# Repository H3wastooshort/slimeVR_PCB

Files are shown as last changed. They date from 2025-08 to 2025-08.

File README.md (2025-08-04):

# some kind of SlimeVR project

a rendered animation of the PCB roatating

## Schematic
the schematic

## PCB
a rendered image of the PCB front
a rendered image of the PCB back

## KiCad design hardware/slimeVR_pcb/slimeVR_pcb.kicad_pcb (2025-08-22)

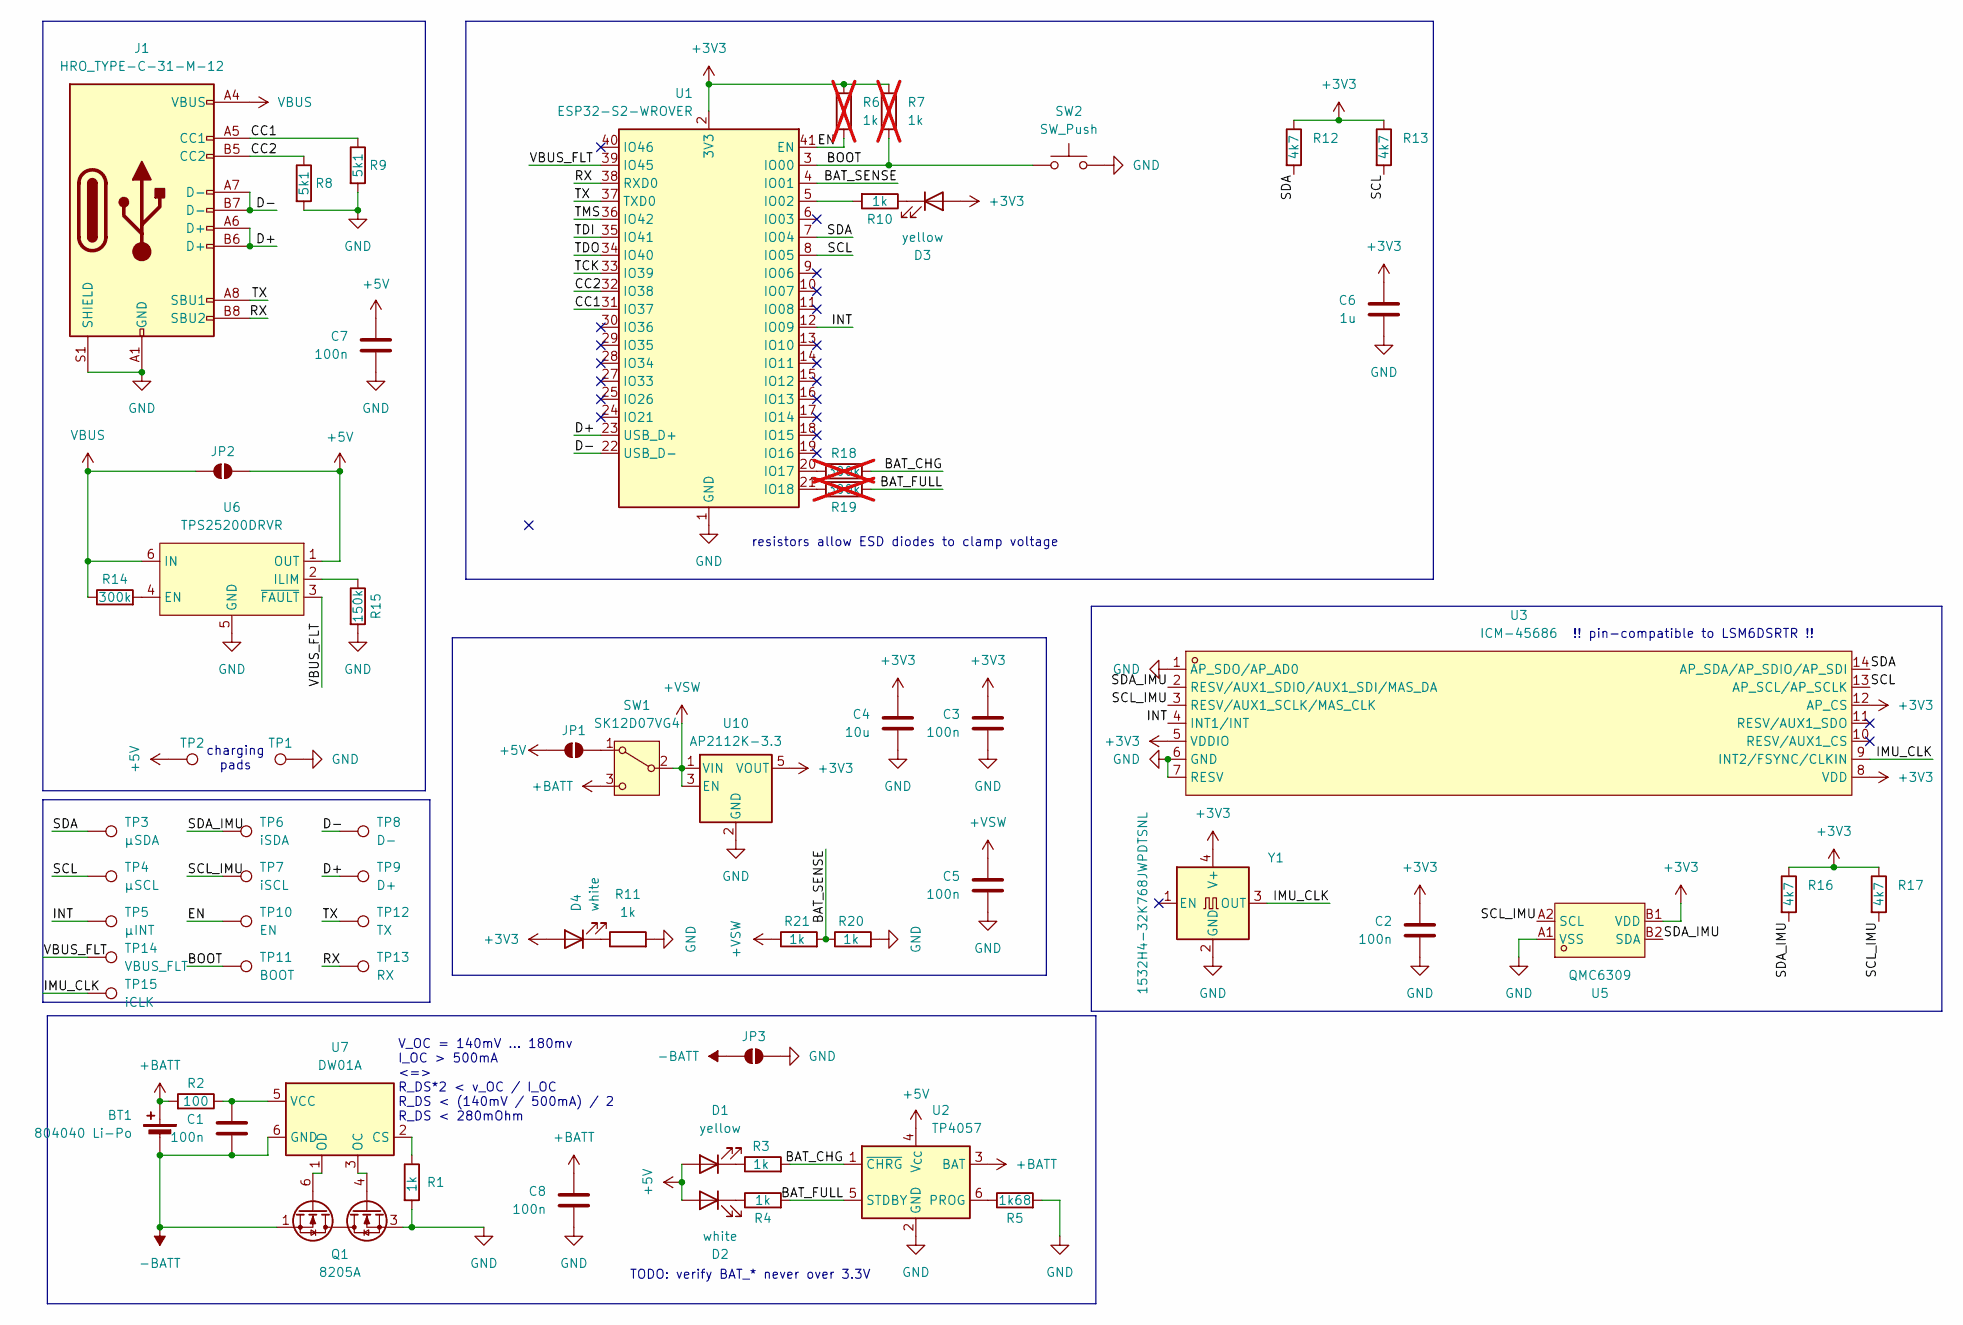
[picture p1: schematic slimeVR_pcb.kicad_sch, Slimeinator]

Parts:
BT1: 804040 Li-Po; JST_EH_B2B-EH-A_1x02_P2.50mm_Vertical
C1, C2, C3, C5, C7, C8: 100n; C_0603_1608Metric_Pad1.08x0.95mm_HandSolder; LCSC C14663
C4: 10u; C_0603_1608Metric_Pad1.08x0.95mm_HandSolder; LCSC C19702
C6: 1u; C_0603_1608Metric_Pad1.08x0.95mm_HandSolder; LCSC C15849
D1, D3: yellow; LED_0805_2012Metric_Pad1.15x1.40mm_HandSolder; LCSC C2296
D2, D4: white; LED_0805_2012Metric_Pad1.15x1.40mm_HandSolder; LCSC C34499
J1: HRO_TYPE-C-31-M-12; USB_C_Receptacle_HRO_TYPE-C-31-M-12; LCSC Part C165948
JP1, JP2, JP3: SolderJumper_2_Open; SolderJumper-2_P1.3mm_Open_TrianglePad1.0x1.5mm
Q1: 8205A; SOT-23-6; LCSC Part C2762931
R1, R3, R4, R10, R11, R20, R21: 1k; R_0603_1608Metric_Pad0.98x0.95mm_HandSolder; LCSC C21190
R2: 100; R_0603_1608Metric_Pad0.98x0.95mm_HandSolder; LCSC C22775
R5: 1k68; R_0603_1608Metric_Pad0.98x0.95mm_HandSolder; LCSC C4177
R6, R7: 1k; R_0603_1608Metric_Pad0.98x0.95mm_HandSolder; LCSC C21190; not fitted
R8, R9: 5k1; R_0603_1608Metric_Pad0.98x0.95mm_HandSolder; LCSC C23186
R12, R13, R16, R17: 4k7; R_0603_1608Metric_Pad0.98x0.95mm_HandSolder; LCSC C23162
R14: 300k; R_0603_1608Metric_Pad0.98x0.95mm_HandSolder; LCSC C23024
R15: 150k; R_0603_1608Metric_Pad0.98x0.95mm_HandSolder; LCSC C22807
R18, R19: 300k; R_0603_1608Metric_Pad0.98x0.95mm_HandSolder; LCSC C23024; not fitted
SW1: SK12D07VG4; SW_Slide_SPDT_Angled_CK_OS102011MA1Q; LCSC Part C393937
SW2: SW_Push; SW_Push_1P1T_NO_CK_KSC7xxJ
TP1: GND; TestPoint_Pad_4.0x4.0mm
TP2: +5V; TestPoint_Pad_4.0x4.0mm
TP3: µSDA; TestPoint_Pad_D1.0mm
TP4: µSCL; TestPoint_Pad_D1.0mm
TP5: µINT; TestPoint_Pad_D1.0mm
TP6: iSDA; TestPoint_Pad_D1.0mm
TP7: iSCL; TestPoint_Pad_D1.0mm
TP8: D-; TestPoint_Pad_D1.0mm
TP9: D+; TestPoint_Pad_D1.0mm
TP10: EN; TestPoint_Pad_D1.0mm
TP11: BOOT; TestPoint_Pad_D1.0mm
TP12: TX; TestPoint_Pad_D1.0mm
TP13: RX; TestPoint_Pad_D1.0mm
TP14: VBUS_FLT; TestPoint_Pad_D1.0mm
TP15: iCLK; TestPoint_Pad_D1.0mm
U1: ESP32-S2-WROVER
U2: TP4057; TSOT-23-6; LCSC Part C725791
U3: ICM-45686; LGA-14_L3.0-W2.5-P0.50-TL; LCSC Part C22459454
U5: QMC6309; X1-WLB0808-4_L0.8-W0.8-P0.40-TL; LCSC Part C5439871
U6: TPS25200DRVR; WSON-6-1EP_2x2mm_P0.65mm_EP1x1.6mm; LCSC Part C128401
U7: DW01A; SOT-23-6; LCSC Part C2927799
U10: AP2112K-3.3; SOT-23-5; LCSC Part C51118
Y1: 1532H4-32K768JWPDTSNL; OSC-SMD_4P-L3.2-W2.5-CJ13-320001210A20; LCSC C5383164

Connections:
+3V3: C2.1, C3.1, C4.1, C6.1, D3.2 (A), D4.2 (A), R6.1, R7.1, R12.1, R13.1, R16.1, R17.1, U1.2 (3V3), U3.5 (VDDIO), U3.8 (VDD), U3.12 (AP_CS), U5.B1 (VDD), U10.5 (VOUT), Y1.4 (V+)
+5V: C7.1, D1.2 (A), D2.2 (A), JP1.1 (A), JP2.2 (B), TP2.1, U2.4 (V_{CC}), U6.1 (OUT)
+BATT: BT1.1 (+), C8.1, R2.2, SW1.3 (C), U2.3 (BAT)
+VSW: C5.1, R21.1, SW1.2 (B), U10.1 (VIN), U10.3 (EN)
-BATT: BT1.2 (-), C1.2, JP3.2 (B), Q1.1 (S1), U7.6 (GND)
/BAT_CHG: R3.2, R18.2, U2.1 (~CHRG)
/BAT_FULL: R4.2, R19.2, U2.5 (STDBY)
/BAT_SENSE: R20.1, R21.2, U1.4 (IO01)
/BOOT: R7.2, SW2.2, TP11.1, U1.3 (IO00)
/CC1: J1.A5 (CC1), R9.1, U1.31 (IO37)
/CC2: J1.B5 (CC2), R8.1, U1.32 (IO38)
/D+: J1.A6 (D+), J1.B6 (D+), TP9.1, U1.23 (USB_D+)
/D-: J1.A7 (D-), J1.B7 (D-), TP8.1, U1.22 (USB_D-)
/EN: R6.2, TP10.1, U1.41 (EN)
/IMU_CLK: TP15.1, U3.9 (INT2/FSYNC/CLKIN), Y1.3 (OUT)
/INT: TP5.1, U1.12 (IO09), U3.4 (INT1/INT)
/RX: J1.B8 (SBU2), TP13.1, U1.38 (RXD0)
/SCL: R13.2, TP4.1, U1.8 (IO05), U3.13 (AP_SCL/AP_SCLK)
/SCL_IMU: R17.2, TP7.1, U3.3 (RESV/AUX1_SCLK/MAS_CLK), U5.A2 (SCL)
/SDA: R12.2, TP3.1, U1.7 (IO04), U3.14 (AP_SDA/AP_SDIO/AP_SDI)
/SDA_IMU: R16.2, TP6.1, U3.2 (RESV/AUX1_SDIO/AUX1_SDI/MAS_DA), U5.B2 (SDA)
/TCK: U1.33 (IO39)
/TDI: U1.35 (IO41)
/TDO: U1.34 (IO40)
/TMS: U1.36 (IO42)
/TX: J1.A8 (SBU1), TP12.1, U1.37 (TXD0)
/VBUS_FLT: TP14.1, U1.39 (IO45), U6.3 (~FAULT)
GND: C2.2, C3.2, C4.2, C5.2, C6.2, C7.2, C8.2, J1.A1 (GND), J1.A12 (GND), J1.B1 (GND), J1.B12 (GND), J1.S1 (SHIELD), JP3.1 (A), Q1.3 (S2), R1.2, R5.2, R8.2, R9.2, R11.2, R15.2, R20.2, SW2.1, TP1.1, U1.1 (GND), U1.26 (GND), U1.42 (GND), U1.43 (GND), U2.2 (GND), U3.1 (AP_SDO/AP_AD0), U3.6 (GND), U3.7 (RESV), U5.A1 (VSS), U6.5 (GND), U6.7 (EP), U10.2 (GND), Y1.2 (GND)
unnamed: D1.1 (K), R3.1
unnamed: D2.1 (K), R4.1
unnamed: D3.1 (K), R10.1
unnamed: D4.1 (K), R11.1
unnamed: JP1.2 (B), SW1.1 (A)
unnamed: Q1.6 (G1), U7.1 (OD)
unnamed: Q1.4 (G2), U7.3 (OC)
unnamed: R10.2, U1.5 (IO02)
unnamed: R18.1, U1.20 (IO17)
unnamed: R19.1, U1.21 (IO18)
unnamed: R5.1, U2.6 (PROG)
unnamed: R14.2, U6.4 (EN)
unnamed: R15.1, U6.2 (ILIM)
unnamed: R1.1, U7.2 (CS)
unnamed: C1.1, R2.1, U7.5 (VCC)
VBUS: J1.A4 (VBUS), J1.A9 (VBUS), J1.B4 (VBUS), J1.B9 (VBUS), JP2.1 (A), R14.1, U6.6 (IN)

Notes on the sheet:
!! pin-compatible to LSM6DSRTR !!
V_OC = 140mV ... 180mv I_OC > 500mA <=> R_DS*2 < v_OC / I_OC R_DS < (140mV / 500mA) / 2 R_DS < 280mOhm
TODO: verify BAT_* never over 3.3V
charging pads
resistors allow ESD diodes to clamp voltage

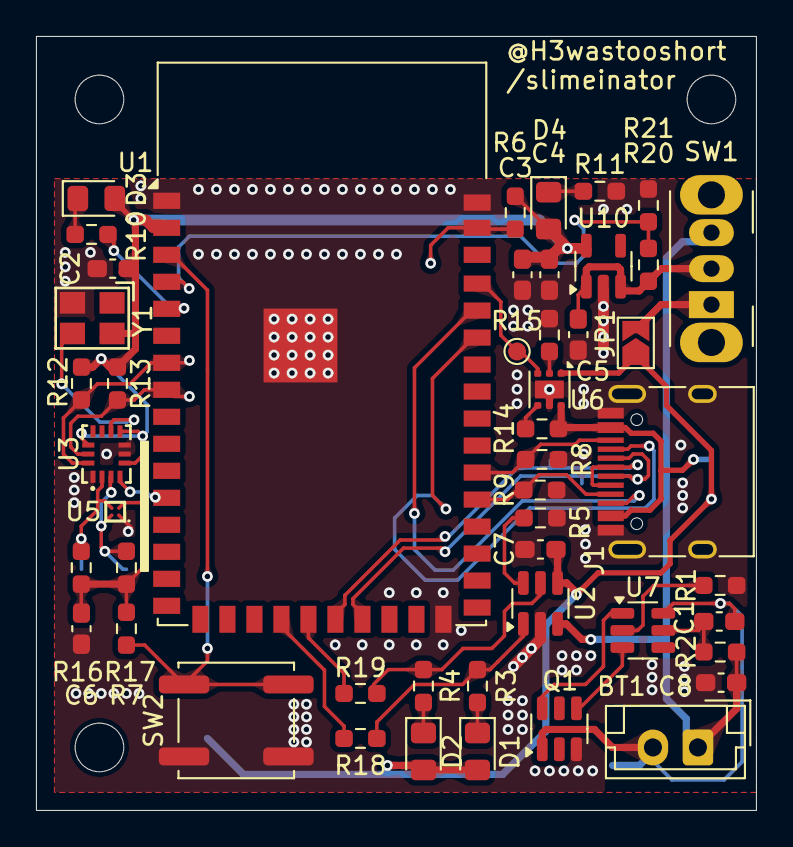
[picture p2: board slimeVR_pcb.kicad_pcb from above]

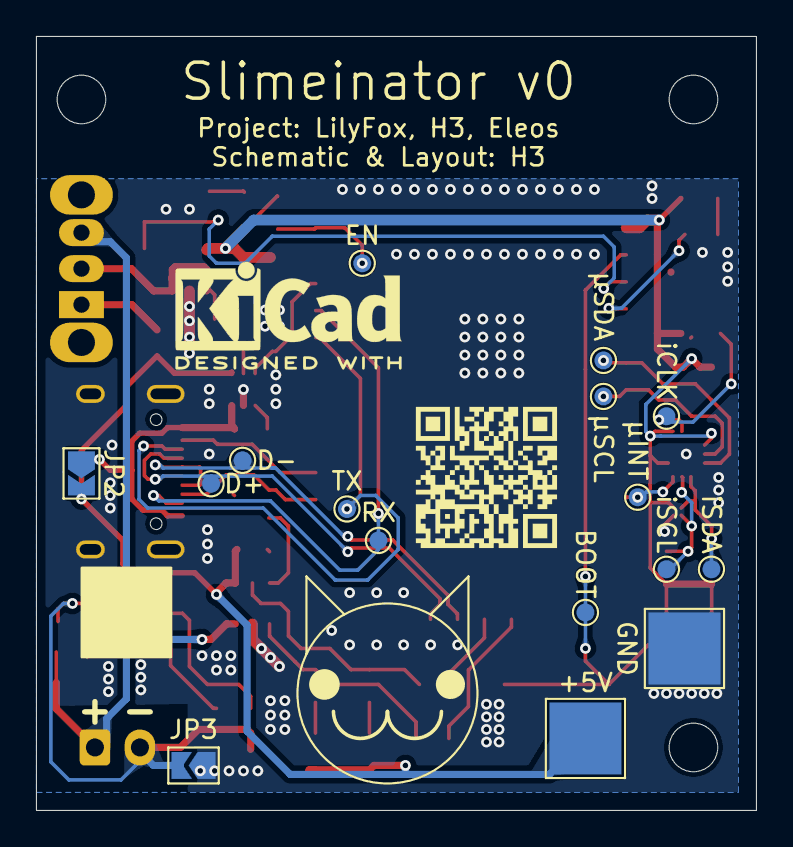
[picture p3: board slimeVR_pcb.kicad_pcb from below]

Board: 2 copper layers, 40.0 x 43.0 mm, 65 parts (17 on the bottom side), 40 nets.

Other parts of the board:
CAT**: PCBcat

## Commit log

2025-05-05 switch to esp32s2
    [slimeVR_pcb.kicad_pcb, slimeVR_pcb.kicad_sch]
2025-07-27 continue pcb, cleanup schematic
    [slimeVR_pcb.kicad_pcb, slimeVR_pcb.kicad_sch]
2025-07-27 add protection circuit
    [slimeVR_pcb.kicad_pcb, slimeVR_pcb.kicad_sch]
2025-07-27 render PCB
2025-07-27 case sensitive urls :grrr:
2025-07-27 cleanup pcb
    [slimeVR_pcb.kicad_pcb, slimeVR_pcb.kicad_sch]
2025-07-27 routed IMU
    [slimeVR_pcb.kicad_pcb, slimeVR_pcb.kicad_sch]
2025-07-27 fix DRC, cleanup
    [slimeVR_pcb.kicad_pcb, slimeVR_pcb.kicad_sch]
2025-07-28 tiredly add testpads
    [slimeVR_pcb.kicad_pcb, slimeVR_pcb.kicad_sch]
2025-07-28 more testpad
    [slimeVR_pcb.kicad_pcb, slimeVR_pcb.kicad_sch]
2025-07-30 implement garfields suggestions, cleanup board, add TPs
    [slimeVR_pcb.kicad_pcb, slimeVR_pcb.kicad_sch]
2025-07-30 add decoupleing caps
    [slimeVR_pcb.kicad_pcb, slimeVR_pcb.kicad_sch]
2025-07-30 cleanup silkscreen, ground unused open-drain
    [slimeVR_pcb.kicad_pcb, slimeVR_pcb.kicad_sch]
2025-07-30 add solderjumpers for charging signals
    [slimeVR_pcb.kicad_pcb, slimeVR_pcb.kicad_sch]
2025-07-30 mark unused esp pins
    [slimeVR_pcb.kicad_sch]
2025-07-31 replace charging signal jumpers with resistors these allow the internal ESD diodes of the ESP32S2 to clamp the valotage to safe levels
    [slimeVR_pcb.kicad_pcb, slimeVR_pcb.kicad_sch]
2025-07-31 add mounting holes
    [slimeVR_pcb.kicad_pcb]
2025-08-01 cleanup, dw01 calc
    [slimeVR_pcb.kicad_pcb, slimeVR_pcb.kicad_sch]
2025-08-02 add debugging footprints
    [slimeVR_pcb.kicad_pcb, slimeVR_pcb.kicad_sch]
2025-08-02 allow reading vbus fault
    [slimeVR_pcb.kicad_pcb, slimeVR_pcb.kicad_sch]
2025-08-04 partsel round 1
    [slimeVR_pcb.kicad_pcb, slimeVR_pcb.kicad_sch]
2025-08-04 add 1mm to 3 sides for sliding into rails in case
    [slimeVR_pcb.kicad_pcb]
2025-08-04 partsel round 2
    [slimeVR_pcb.kicad_pcb, slimeVR_pcb.kicad_sch]
2025-08-04 add silkscreen labels
    [slimeVR_pcb.kicad_pcb]
2025-08-04 fix case-sensitive URL
2025-08-04 add. design rules, pcb cleanup
    [slimeVR_pcb.kicad_pcb]
2025-08-06 allow ESP to read/write CC pins for future use
    [slimeVR_pcb.kicad_pcb, slimeVR_pcb.kicad_sch]
2025-08-06 tried to use an FUSB302 to supply vconn
    [slimeVR_pcb.kicad_pcb, slimeVR_pcb.kicad_sch]
2025-08-06 give up on FUSB302 idea i need to supply power via USB C safely, without adding more comonents i need 2 datalines for i2c i could detect shorting of sbu 1 and sbu 2, then use the CC or D+/D- pins for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
    [slimeVR_pcb.kicad_pcb, slimeVR_pcb.kicad_sch]
2025-08-07 fix typo
    [slimeVR_pcb.kicad_pcb, slimeVR_pcb.kicad_sch]
2025-08-07 actually fix typo...
    [slimeVR_pcb.kicad_pcb]
2025-08-22 fixup partsel, fixup silkscreen
    [slimeVR_pcb.kicad_pcb, slimeVR_pcb.kicad_sch]
2025-08-22 fixup LCSC tags
    [slimeVR_pcb.kicad_pcb]
2025-08-22 add oscillator for IMU
    [slimeVR_pcb.kicad_pcb, slimeVR_pcb.kicad_sch]
2025-08-22 fix osc footprint
    [slimeVR_pcb.kicad_pcb, slimeVR_pcb.kicad_sch]
2025-08-22 silk n stuff
    [slimeVR_pcb.kicad_pcb, slimeVR_pcb.kicad_sch]
2025-08-22 pcb paper size
    [slimeVR_pcb.kicad_pcb]
2025-08-22 add qrcode to repo
    [slimeVR_pcb.kicad_pcb]
